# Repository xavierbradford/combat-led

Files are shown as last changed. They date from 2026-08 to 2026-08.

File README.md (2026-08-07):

# Combat Robotics Arena Lighting

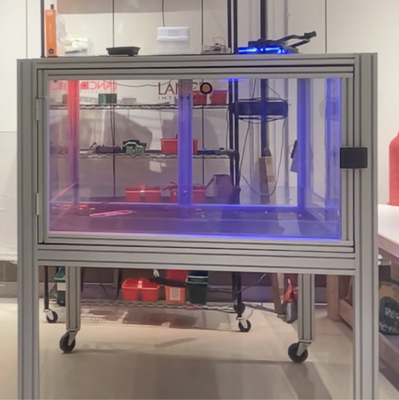
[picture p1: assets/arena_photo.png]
Photo of the arena


The [STEM Coliseum](https://stemcoliseum.org) — where I worked full-time over the summer — runs open antweight combat robotics events, and I thought arena LED effects would make the matches more interesting. The hardware was almost entirely whatever we had lying around the facility, so the choices are unconventional.

I tried to use AI to streamline the development of this project and was surprised that without much help it was able to reverse-engineer the (nonstandard and undocumented) network protocol for the Wi-Fi lights. I used Wireshark to sniff UDP traffic from the proprietary LED control app on my phone to the lights, and described the information I was sending. The AI even automatically determined the parameters in the CRC checksum by writing a Python script to try out common options — very cool!

## Features

- [x] Wi-Fi control of the arena lights
- [x] Web UI
- [x] Infrared control of the match timer
- [x] Impact-reactive lighting effects
- [ ] USB button to advance to the next phase

## Match phases

| Phase | Light & Timer State | Rendering |
| --- | --- | --- |
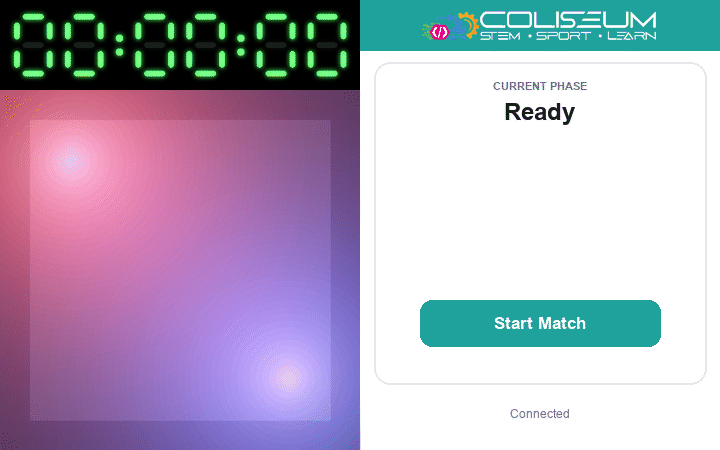
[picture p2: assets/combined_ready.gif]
Ready
| Ready | Red (master) / blue (slave); timer powered on, stopwatch |  |
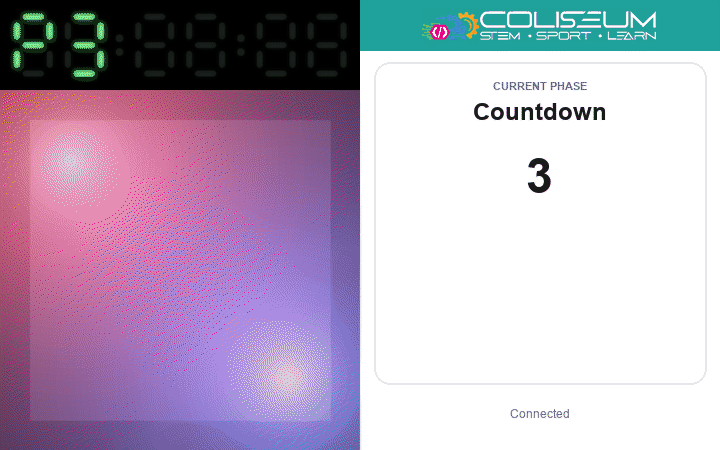
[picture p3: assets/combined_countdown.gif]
Countdown
| Countdown | Red/blue, flashing and fading each second; 3·2·1 countdown |  |
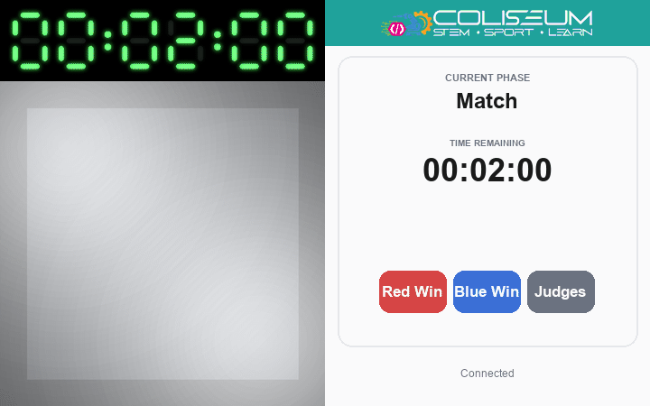
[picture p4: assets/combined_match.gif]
Match
| Match | 100% white, flashing on robot impact; running stopwatch (2 min) |  |
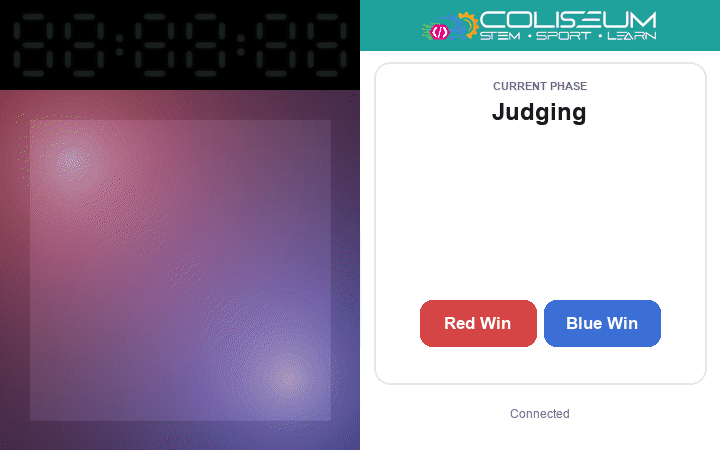
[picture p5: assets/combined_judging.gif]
Judging
| Judging | Red/blue "breathing" alternately; timer off |  |
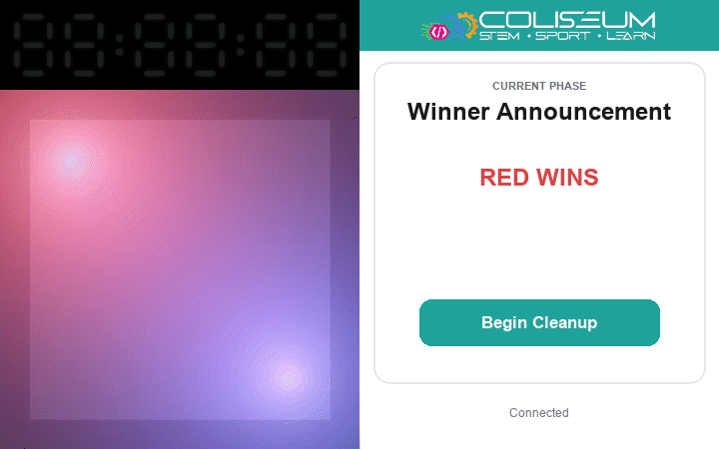
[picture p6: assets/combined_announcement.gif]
Winner Announcement
| Winner Announcement | Alternating, strobe, then hold winner colour; timer off |  |
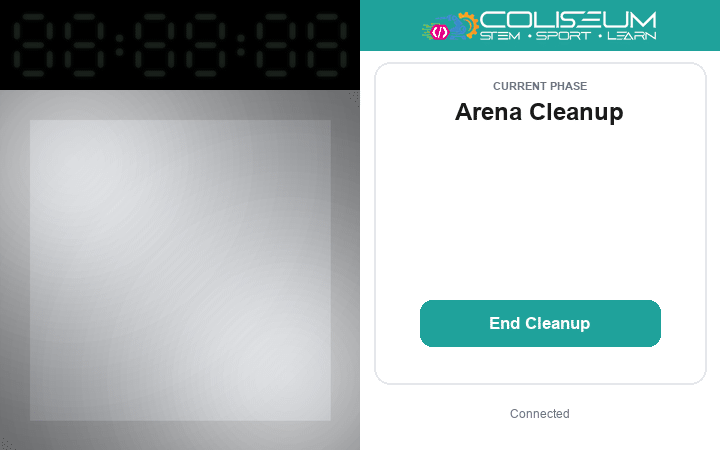
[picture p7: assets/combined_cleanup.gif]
Arena Cleanup
| Arena Cleanup | White, full brightness; timer off |  |

The board boots straight into the Ready phase; after a match it cycles through Arena Cleanup and back to Ready.

Match phase diagram with transitions

## Hardware

- 2× ESP32 dev board — one master, one slave
- 2× Wi-Fi-enabled LED lights (they listen on UDP port 2525)
- Microphone/sound module with analog output (AO) → master GPIO34
- IR transmitter module (e.g. KY-005) → master GPIO4
- Match timer with IR remote
- Jumper wires, breadboard, USB power

The left ESP32 is the master, connected to the microphone, IR transmitter, and (over Wi-Fi) one of the LEDs. The right ESP32 is the slave, connected to the other LED on its separate Wi-Fi network, and receives commands from the master over a serial port.

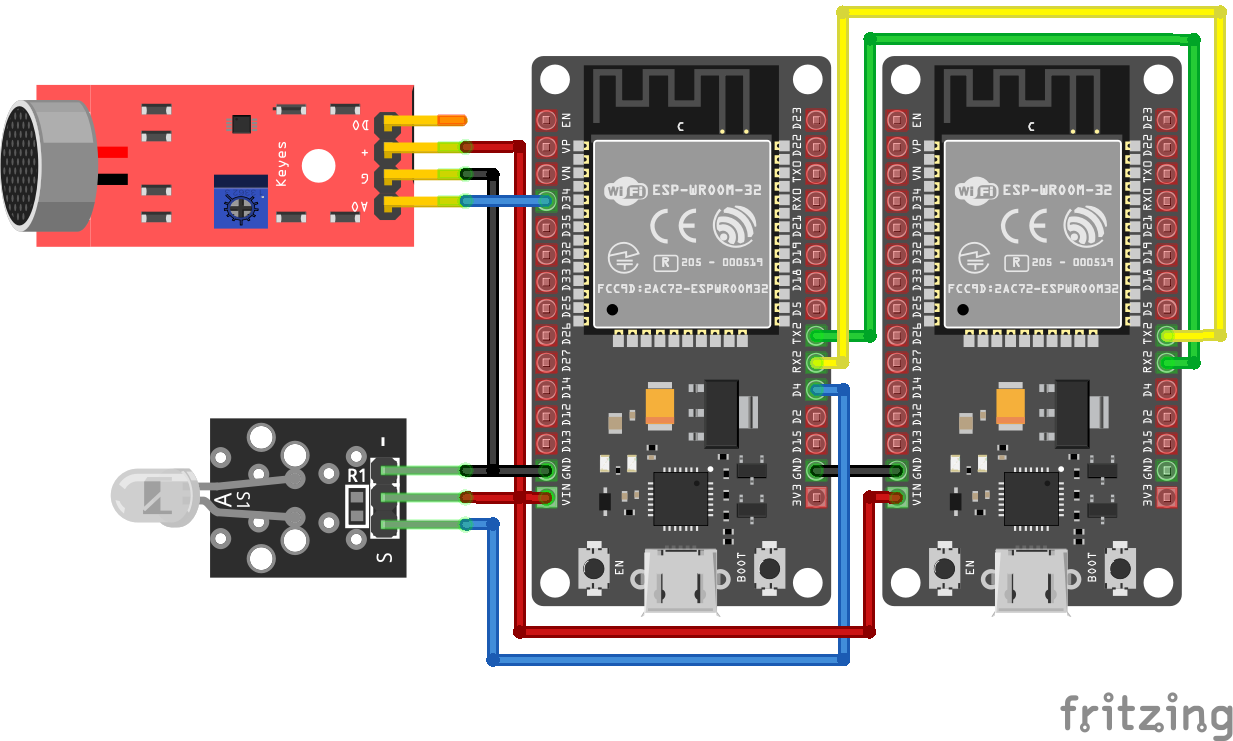
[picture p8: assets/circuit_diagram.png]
Circuit diagram


The master's UART2 connects to the slave's: master TX (GPIO17) → slave RX (GPIO16), master RX (GPIO16) ← slave TX (GPIO17), with a common GND.

## Setup

### Build & flash (no Arduino IDE needed)

You only need Python 3.10+. The first run downloads PlatformIO, the ESP32
toolchain, and the sketch libraries automatically (the master uses ArduinoJson,
AsyncTCP, ESPAsyncWebServer, and IRremote — exact versions are pinned in
`led_master_esp32/platformio.ini`):

```sh
python3 flash.py master          # build + flash the master board
python3 flash.py slave           # build + flash the slave board
python3 flash.py slave --build-only   # compile only, no flashing
python3 flash.py master --monitor     # flash, then open the serial monitor
```

If the board isn't auto-detected, pass its USB port:

```sh
python3 flash.py master --port /dev/tty.usbserial-0001   # macOS / Linux
python3 flash.py slave --port COM3                        # Windows
```

Plug each board into your computer over USB while flashing. Press the board's
`EN`/`RST` button if it doesn't auto-restart afterward.

> `flash.py` works on macOS, Linux, and Windows. Each sketch folder is also a
> self-contained PlatformIO project, so with PlatformIO installed you can run
> `pio run -d led_master_esp32 -t upload` (or `led_slave_esp32`) directly.

### First run

1. Flash the sketch in `led_master_esp32/` to the master board and the one in `led_slave_esp32/` to the slave.
2. Power both boards. Each joins its own light's network (`COMBAT_LED` / `COMBAT_LED2`).
3. Connect to the `COMBAT_LED` network on your phone (password `gvm_admin`).
4. Load the web UI at `http://192.168.4.2`.
> [!TIP]
> If it's not loading, try disabling your mobile data. Your phone might have realised the `COMBAT_LED` network doesn't have access to WAN, and might be trying to resolve the IP through mobile data.
5. Continue through the phases of the match. When you finish one match, it cycles back and is ready for another.

## Customizing

- **Match timings** — `COUNTDOWN_MS` and `MATCH_MS` in `led_master_esp32/led_master_esp32.ino`.
- **Phases and transitions** — the `Phase` enum, `applyAction()`, and the `tickCountdown()`/`tickMatch()` functions define the state machine. The action strings returned by `buttonDefs()` in `led_master_esp32/arena_ui.h` (e.g. `startMatch`, `redWin`, `judges`) must match the cases handled by `applyAction()`.
- **Per-phase lighting** — `updateLightingForPhase()` sets the look when a phase starts; colours, hues, and brightness defaults are hardcoded there (e.g. red = 0°, blue = 240°). `processLightingAnimations()` drives the animated effects (countdown flash, judging "breathing", announcement strobe). Impact flashes during the match are handled by `processMicBrightness()`, tuned by the constants in the `mic` namespace (e.g. `HIT_THRESHOLD`, `FLASH_HOLD_MS`).
- **IR timer control** — the `display` namespace maps the match timer's remote buttons (`BTN_*` constants) and decides when they're pressed in `onPhaseEntered()` and `onCountdownTick()`.
- **Web UI** — all the HTML/CSS/JS is a single header, `led_master_esp32/arena_ui.h`.
- **Networks / Wi-Fi credentials** — the SSID, password, static IP, gateway, subnet, DNS, and bulb broadcast address are all at the top of `led_master_esp32/led_master_esp32.ino` (master) and `led_slave_esp32/led_slave_esp32.ino` (slave).
- **Wired link and adding another light** — the master talks to the slave over UART2 (GPIO16/17 by default) using the framed serial protocol in the `wirelink` namespace; the slave forwards `(selector, value)` frames to its own light. Another slave board is all you'd need to drive a third light; update `linkRxPin`/`linkTxPin`/`linkBaud` in both sketches if you change the wiring.

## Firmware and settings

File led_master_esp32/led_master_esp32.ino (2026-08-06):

/*
 * Dependencies:
 *  Benoit - ArduinoJson@6.21.6
 *  ESP32Async - AsyncTCP@3.5.0
 *  ESP32Async - ESP Async TCP@2.0.0
 *  ESP32Async - ESP Async WebServer@3.11.2
 *  IRremote by shirriff, z3t0, ArminJo v4.7.1
 *
 * These are pinned in platformio.ini for `python3 flash.py master` builds.
 * The sketches need the ESP32 Arduino core 3.x API (<NetworkUdp.h>); the
 * PlatformIO build pulls core 3.x from the pioarduino platform.
 *
 * MASTER ESP32 - connects to its own light's WiFi network, controls that
 * light directly (same protocol as the original app), forwards every
 * command over a wired UART link to the slave board (which relays it to
 * the second light), and hosts a mobile-first match-control web UI.
 */

#include <Arduino.h>
#include <WiFi.h>
#include <NetworkUdp.h>
#include <AsyncTCP.h>
#include <ESPAsyncWebServer.h>
#include <ArduinoJson.h>
#include <IRremote.hpp>
#include "arena_ui.h"

// Forward declarations so the PlatformIO/Arduino-IDE automatic
// function-prototype generators can resolve these types: they are defined
// further down in this file, inside their own namespaces, but the
// generated prototypes are emitted at the top of the file.
namespace arena { struct Snapshot; }
namespace display { enum Button : uint8_t; }

// ---------------------------------------------------------------------
// WiFi credentials
// ---------------------------------------------------------------------
const char *networkName = "COMBAT_LED";
const char *networkPswd = "gvm_admin";

const char *bulbBroadcastAddress = "192.168.4.255";
const uint16_t bulbPort = 2525;

// Static IP so the arena web UI is always reachable at the same address,
// regardless of what IP the bulb's AP (DHCP) hands out.
IPAddress arenaIp(192, 168, 4, 2);
IPAddress arenaGateway(192, 168, 4, 1);
IPAddress arenaSubnet(255, 255, 255, 0);
IPAddress arenaDns(192, 168, 4, 1);

// ---------------------------------------------------------------------
// Serial link to slave board
// ---------------------------------------------------------------------
const unsigned long linkBaud = 3000000;
const int linkRxPin = 16; // GPIO16 = RX2
const int linkTxPin = 17; // GPIO17 = TX2
HardwareSerial SerialLink(2);

boolean connected = false;
NetworkUDP udp;

AsyncWebServer server(80);
AsyncWebSocket ws("/ws");

// ---------------------------------------------------------------------
// LED protocol
// ---------------------------------------------------------------------
namespace led {

// See the forward declarations at the top of this file. The prototype
// generators hoist function declarations to this point, and these bring
// the namespaced types into scope so those hoisted declarations compile.
using arena::Snapshot;
using display::Button;

constexpr uint8_t HEADER[7] = {0x4C, 0x54, 0x09, 0x00, 0x30, 0x57, 0x00};
constexpr uint8_t FIXED_MID = 0x01;

enum class Type : uint8_t {
  Power,
  Channel,
  Hue,
  Brightness,
  Cct,
  Saturation,
};

inline uint16_t crc16CcittFalse(const uint8_t *data, size_t len) {
  uint16_t crc = 0x0000;
  for (size_t i = 0; i < len; i++) {
    crc ^= ((uint16_t)data[i]) << 8;
    for (int b = 0; b < 8; b++) {
      if (crc & 0x8000) {
        crc = (crc << 1) ^ 0x1021;
      } else {
        crc <<= 1;
      }
    }
  }
  return crc;
}

struct Command {
  Type type;
  uint8_t value;

  static Command power(bool on) {
    return Command{Type::Power, (uint8_t)(on ? 1 : 0)};
  }

  static Command channel(uint8_t ch) {
    return Command{Type::Channel, ch};
  }

  static Command hue(uint8_t raw) {
    return Command{Type::Hue, (uint8_t)min((uint32_t)raw, (uint32_t)71)};
  }

  static Command hueFromDegrees(uint16_t degrees) {
    uint16_t deg = degrees % 360;
    uint8_t raw = (uint8_t)min((uint32_t)((deg + 2) / 5), (uint32_t)71);
    return hue(raw);
  }

  static Command brightness(uint8_t percent) {
    return Command{Type::Brightness, (uint8_t)min((uint32_t)percent, (uint32_t)100)};
  }

  static Command cct(uint8_t raw) {
    return Command{Type::Cct, raw};
  }

  static Command cctFromKelvin(uint32_t kelvin) {
    uint32_t raw = (kelvin + 50) / 100;
    if (raw > 255) raw = 255;
    return cct((uint8_t)raw);
  }

  static Command saturation(uint8_t percent) {
    return Command{Type::Saturation, (uint8_t)min((uint32_t)percent, (uint32_t)100)};
  }

  uint8_t selector() const {
    switch (type) {
      case Type::Power:      return 0x00;
      case Type::Channel:    return 0x01;
      case Type::Brightness: return 0x02;
      case Type::Cct:        return 0x03;
      case Type::Hue:        return 0x04;
      case Type::Saturation: return 0x05;
    }
    return 0x00;
  }

  uint8_t valueByte() const {
    return value;
  }

  void dataBytes(uint8_t out[10]) const {
    memcpy(out, HEADER, 7);
    out[7] = selector();
    out[8] = FIXED_MID;
    out[9] = valueByte();
  }

  void toBytes(uint8_t out[12]) const {
    uint8_t data[10];
    dataBytes(data);
    uint16_t crc = crc16CcittFalse(data, 10);
    memcpy(out, data, 10);
    out[10] = (uint8_t)(crc >> 8);
    out[11] = (uint8_t)(crc & 0xFF);
  }

  String toHexString() const {
    uint8_t bytes[12];
    toBytes(bytes);
    char buf[25];
    for (int i = 0; i < 12; i++) {
      sprintf(&buf[i * 2], "%02X", bytes[i]);
    }
    buf[24] = '\0';
    return String(buf);
  }

  bool send(NetworkUDP &sock, const char *addr = nullptr, uint16_t port = 0) const {
    if (addr == nullptr) addr = bulbBroadcastAddress;
    if (port == 0) port = bulbPort;

    String hex = toHexString();
    sock.beginPacket(addr, port);
    sock.write((const uint8_t *)hex.c_str(), hex.length());
    return sock.endPacket() == 1;
  }
};

} // namespace led

// ---------------------------------------------------------------------
// Wired Link Protocol
// ---------------------------------------------------------------------
namespace wirelink {

constexpr uint8_t FRAME_START = 0xA5;

inline uint8_t checksum(uint8_t sel, uint8_t val) {
  return FRAME_START ^ sel ^ val;
}

inline void sendFrame(HardwareSerial &s, uint8_t sel, uint8_t val) {
  uint8_t frame[4] = {FRAME_START, sel, val, checksum(sel, val)};
  s.write(frame, 4);
}

} // namespace wirelink

void sendAndForward(const led::Command &cmd) {
  cmd.send(udp);
  wirelink::sendFrame(SerialLink, cmd.selector(), cmd.valueByte());
}

void send(const led::Command &cmd) {
  cmd.send(udp);
}

void forward(const led::Command &cmd) {
  wirelink::sendFrame(SerialLink, cmd.selector(), cmd.valueByte());
}

// White is produced in RGB mode via saturation(0) - the CCT command
// (selector 0x03) is ignored by these bulbs and leaves them in whatever
// colour they were showing, so it can't be used for white.
void setWhite(uint8_t brightness) {
  sendAndForward(led::Command::saturation(0));
  sendAndForward(led::Command::brightness(brightness));
}

// Defined here so display helpers below can use the enumerators.
namespace arena { enum class Phase : uint8_t { Cleanup, Ready, Countdown, Match, Judging, Announcement }; }

// ---------------------------------------------------------------------
// Fitness Timer Display (IR remote)
// ---------------------------------------------------------------------
namespace display {

// KY-005 S (Signal) pin. On ESP32 any GPIO works for IR output.
constexpr int IR_SEND_PIN = 4;
constexpr uint8_t REMOTE_ADDRESS = 0x01;

enum Button : uint8_t {
  BTN_POWER       = 0x0A,
  BTN_EDIT        = 0x0B,
  BTN_CLOCK       = 0x53,
  BTN_UP          = 0x52,
  BTN_DOWN        = 0x51,
  BTN_STOPWATCH   = 0x50,
  BTN_EMOM        = 0x1B,
  BTN_TABATA      = 0x4B,
  BTN_HIIT        = 0x54,
  BTN_FGB         = 0x4A,
  BTN_ALARM_UP    = 0x43,
  BTN_COLOR_DOWN  = 0x42,
  BTN_START       = 0x5E,
  BTN_RESET       = 0x5D,
  BTN_RESTART     = 0x5B,
  BTN_STOP        = 0x59,
  BTN_ENTER       = 0x5A,
  BTN_EXIT        = 0x41,
  BTN_MUTE        = 0x1A,
  BTN_PREPARATION = 0x57,
  BTN_12_24H      = 0x4F,
  BTN_NUM_0       = 0x03,
  BTN_NUM_1       = 0x0E,
  BTN_NUM_2       = 0x06,
  BTN_NUM_3       = 0x0F,
  BTN_NUM_4       = 0x12,
  BTN_NUM_5       = 0x07,
  BTN_NUM_6       = 0x13,
  BTN_NUM_7       = 0x16,
  BTN_NUM_8       = 0x02,
  BTN_NUM_9       = 0x17,
};

constexpr size_t IR_QUEUE_SIZE = 8;
constexpr uint16_t IR_GAP_MS = 200;

uint8_t irQueue[IR_QUEUE_SIZE];
size_t irQueueHead = 0;
size_t irQueueTail = 0;
unsigned long lastIrSendMs = 0;

bool displayPoweredOn = true;
int lastCountdownDigitSent = -1;

bool enqueue(Button button) {
  size_t next = (irQueueHead + 1) % IR_QUEUE_SIZE;
  if (next == irQueueTail) return false;
  irQueue[irQueueHead] = static_cast<uint8_t>(button);
  irQueueHead = next;
  return true;
}

bool dequeue(uint8_t &button) {
  if (irQueueHead == irQueueTail) return false;
  button = irQueue[irQueueTail];
  irQueueTail = (irQueueTail + 1) % IR_QUEUE_SIZE;
  return true;
}

void begin() {
  IrSender.begin(IR_SEND_PIN);
}

void processQueue() {
  unsigned long now = millis();
  if ((now - lastIrSendMs) < IR_GAP_MS) return;

  uint8_t button;
  if (dequeue(button)) {
    Serial.print("IR send 0x");
    Serial.println(button, HEX);
    IrSender.sendNEC(REMOTE_ADDRESS, button, 0);
    lastIrSendMs = now;
  }
}

void onPhaseEntered(arena::Phase newPhase, arena::Phase oldPhase) {
  if (newPhase == arena::Phase::Countdown) {
    lastCountdownDigitSent = -1;
  }

  switch (newPhase) {
    case arena::Phase::Ready:
      if (oldPhase == arena::Phase::Cleanup) {
        if (!displayPoweredOn) {
          enqueue(BTN_POWER);
          displayPoweredOn = true;
        }
        enqueue(BTN_STOPWATCH);
      }
      break;

    case arena::Phase::Match:
      if (oldPhase == arena::Phase::Countdown) {
        enqueue(BTN_DOWN);
        enqueue(BTN_START);
      }
      break;

    case arena::Phase::Judging:
      if (oldPhase == arena::Phase::Match && displayPoweredOn) {
        enqueue(BTN_POWER);
        displayPoweredOn = false;
      }
      break;

    case arena::Phase::Announcement:
      if (oldPhase == arena::Phase::Match && displayPoweredOn) {
        enqueue(BTN_POWER);
        displayPoweredOn = false;
      }
      break;

    default:
      break;
  }
}

void onCountdownTick(unsigned long remainingMs) {
  int secs = (int)((remainingMs + 999) / 1000); // ceil
  if (secs < 1 || secs > 3 || secs == lastCountdownDigitSent) return;

  Button digit;
  switch (secs) {
    case 3: digit = BTN_NUM_3; break;
    case 2: digit = BTN_NUM_2; break;
    case 1: digit = BTN_NUM_1; break;
    default: return;
  }

  enqueue(digit);
  lastCountdownDigitSent = secs;
}

} // namespace display

// ---------------------------------------------------------------------
// Arena State Machine
// ---------------------------------------------------------------------
namespace arena {

enum class Winner : uint8_t { None, Red, Blue };

struct MatchState {
  // Boot straight into Ready so a fresh event starts on the starting
  // phase; Cleanup is still entered after each match via "Begin Cleanup".
  Phase phase = Phase::Ready;
  Winner winner = Winner::None;
  uint32_t version = 0;
};

struct Snapshot {
  Phase phase;
  Winner winner;
  uint32_t version;
  unsigned long remainingMs;
  unsigned long matchRemainingMs;
};

const unsigned long COUNTDOWN_MS = 3000;
const unsigned long MATCH_MS = 120000; // 2 minutes

MatchState matchState;
unsigned long countdownStartedAt = 0;
unsigned long matchStartedAt = 0;
portMUX_TYPE stateMux = portMUX_INITIALIZER_UNLOCKED;

const char *phaseName(Phase p) {
  switch (p) {
    case Phase::Cleanup:      return "Cleanup";
    case Phase::Ready:        return "Ready";
    case Phase::Countdown:    return "Countdown";
    case Phase::Match:        return "Match";
    case Phase::Judging:      return "Judging";
    case Phase::Announcement: return "Announcement";
  }
  return "Unknown";
}

const char *winnerName(Winner w) {
  switch (w) {
    case Winner::Red:  return "red";
    case Winner::Blue: return "blue";
    default:           return "none";
  }
}

unsigned long remainingCountdownMsLocked() {
  if (matchState.phase != Phase::Countdown) return 0;
  unsigned long elapsed = millis() - countdownStartedAt;
  return (elapsed >= COUNTDOWN_MS) ? 0 : (COUNTDOWN_MS - elapsed);
}

unsigned long remainingMatchMsLocked() {
  if (matchState.phase != Phase::Match) return 0;
  unsigned long elapsed = millis() - matchStartedAt;
  return (elapsed >= MATCH_MS) ? 0 : (MATCH_MS - elapsed);
}

Snapshot snapshot() {
  Snapshot s;
  portENTER_CRITICAL(&stateMux);
  s.phase = matchState.phase;
  s.winner = matchState.winner;
  s.version = matchState.version;
  s.remainingMs = remainingCountdownMsLocked();
  s.matchRemainingMs = remainingMatchMsLocked();
  portEXIT_CRITICAL(&stateMux);
  return s;
}

String toJson(const Snapshot &s) {
  StaticJsonDocument<256> doc;
  doc["phase"] = phaseName(s.phase);
  doc["winner"] = winnerName(s.winner);
  doc["version"] = s.version;
  doc["countdownRemainingMs"] = s.remainingMs;
  doc["matchRemainingMs"] = s.matchRemainingMs;
  doc["serverTime"] = millis();
  String out;
  serializeJson(doc, out);
  return out;
}

bool applyAction(const String &action, uint32_t expectedVersion, Snapshot &outSnap) {
  bool applied = false;
  portENTER_CRITICAL(&stateMux);
  if (matchState.version == expectedVersion) {
    switch (matchState.phase) {
      case Phase::Cleanup:
        if (action == "endCleanup") {
          matchState.phase = Phase::Ready;
          applied = true;
        }
        break;
      case Phase::Ready:
        if (action == "startMatch") {
          matchState.phase = Phase::Countdown;
          matchState.winner = Winner::None;
          countdownStartedAt = millis();
          applied = true;
        }
        break;
      case Phase::Countdown:
        break;
      case Phase::Match:
        if (action == "redWin") {
          matchState.phase = Phase::Announcement;
          matchState.winner = Winner::Red;
          applied = true;
        } else if (action == "blueWin") {
          matchState.phase = Phase::Announcement;
          matchState.winner = Winner::Blue;
          applied = true;
        } else if (action == "judges") {
          matchState.phase = Phase::Judging;
          applied = true;
        }
        break;
      case Phase::Judging:
        if (action == "redWin") {
          matchState.phase = Phase::Announcement;
          matchState.winner = Winner::Red;
          applied = true;
        } else if (action == "blueWin") {
          matchState.phase = Phase::Announcement;
          matchState.winner = Winner::Blue;
          applied = true;
        }
        break;
      case Phase::Announcement:
        if (action == "newMatch") {
          matchState.phase = Phase::Cleanup;
          matchState.winner = Winner::None;
          applied = true;
        }
        break;
    }
    if (applied) matchState.version++;
  }
    outSnap.phase = matchState.phase;
    outSnap.winner = matchState.winner;
    outSnap.version = matchState.version;
    outSnap.remainingMs = remainingCountdownMsLocked();
    outSnap.matchRemainingMs = remainingMatchMsLocked();
    portEXIT_CRITICAL(&stateMux);
    return applied;
}

bool tickCountdown() {
  bool changed = false;
  portENTER_CRITICAL(&stateMux);
  if (matchState.phase == Phase::Countdown &&
      (millis() - countdownStartedAt) >= COUNTDOWN_MS) {
    matchState.phase = Phase::Match;
    matchState.version++;
    matchStartedAt = millis();
    changed = true;
  }
  portEXIT_CRITICAL(&stateMux);
  return changed;
}

bool tickMatch() {
  bool changed = false;
  portENTER_CRITICAL(&stateMux);
  if (matchState.phase == Phase::Match &&
      (millis() - matchStartedAt) >= MATCH_MS) {
    matchState.phase = Phase::Judging;
    matchState.version++;
    changed = true;
  }
  portEXIT_CRITICAL(&stateMux);
  return changed;
}

} // namespace arena

void updateLightingForPhase(const arena::Snapshot &snap);

// ---------------------------------------------------------------------
// Arena Web Server & Websocket setup
// ---------------------------------------------------------------------
bool arenaServerStarted = false;

void startArenaServer() {
  if (arenaServerStarted) return;
  arenaServerStarted = true;

  server.on("/", HTTP_GET, [](AsyncWebServerRequest *request) {
    request->send_P(200, "text/html", INDEX_HTML);
  });

  server.on("/api/state", HTTP_GET, [](AsyncWebServerRequest *request) {
    request->send(200, "application/json", arena::toJson(arena::snapshot()));
  });

  server.on(
      "/api/action", HTTP_POST,
      [](AsyncWebServerRequest *request) {},
      nullptr,
      [](AsyncWebServerRequest *request, uint8_t *data, size_t len, size_t index, size_t total) {
        if (index == 0) {
          request->_tempObject = new String();
        }
        String *body = reinterpret_cast<String *>(request->_tempObject);
        body->concat((const char *)data, len);
        if (index + len != total) return;

        StaticJsonDocument<128> in;
        DeserializationError err = deserializeJson(in, *body);
        String action = err ? String("") : String((const char *)(in["action"] | ""));
        uint32_t expectedVersion = err ? 0 : (uint32_t)(in["version"] | 0);
        delete body;
        request->_tempObject = nullptr;

        arena::Snapshot snap;
        bool applied = arena::applyAction(action, expectedVersion, snap);
        String out = arena::toJson(snap);

        request->send(applied ? 200 : 409, "application/json", out);
        if (applied) {
          ws.textAll(out);
          updateLightingForPhase(snap);
        }
      });

  ws.onEvent([](AsyncWebSocket *server, AsyncWebSocketClient *client, AwsEventType type,
                void *arg, uint8_t *data, size_t len) {
    if (type == WS_EVT_CONNECT) {
      client->text(arena::toJson(arena::snapshot()));
    }
  });
  server.addHandler(&ws);

  server.begin();
  Serial.println("Arena web UI started");
}

// ---------------------------------------------------------------------
// Microphone Sound Detection
// ---------------------------------------------------------------------
// The sound sensor module's AO output is an audio waveform riding on a
// DC quiescent point. Loudness is measured as the peak-to-peak swing of
// the ADC samples over a rolling window - the same AMP value printed by
// the sound_sensor_test sketch. During a Match the lights sit at a
// default 100% white; any sound above the threshold snaps them to a
// full-brightness red/blue flash for at least FLASH_HOLD_MS.
namespace mic {

constexpr int AO_PIN = 34;                // ADC1_CH6, input-only, unused by master
constexpr unsigned long WINDOW_MS = 40;   // rolling loudness window
constexpr unsigned long SAMPLE_INTERVAL_MS = 2; // ~500 Hz sampling
constexpr int HIT_THRESHOLD = 60;         // amplitude that counts as a hit
constexpr unsigned long FLASH_HOLD_MS = 50; // minimum flash duration

// Default (quiet) look for the Match phase.
constexpr int DEFAULT_BRIGHTNESS = 100;

int minVal = 4095;
int maxVal = 0;
unsigned long lastSampleMs = 0;
unsigned long windowStartMs = 0;

void begin() {
  analogReadResolution(12);
  analogSetPinAttenuation(AO_PIN, ADC_11db);
}

// Call once per loop() pass. Returns the loudness of the last completed
// sampling window, or -1 if no window has finished since the last call.
int readAmplitude() {
  unsigned long now = millis();
  if ((now - lastSampleMs) < SAMPLE_INTERVAL_MS) return -1;
  lastSampleMs = now;

  int v = analogRead(AO_PIN);
  if (v < minVal) minVal = v;
  if (v > maxVal) maxVal = v;

  if ((now - windowStartMs) < WINDOW_MS) return -1;

  int amplitude = maxVal - minVal;
  minVal = 4095;
  maxVal = 0;
  windowStartMs = now;
  return amplitude;
}

} // namespace mic

// ---------------------------------------------------------------------
// Non-Blocking Lighting State Controller
// ---------------------------------------------------------------------
enum class AnnounceStep { Alternating, Strobe, HoldWinner };
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
void loop() {
  if (!connected) return;

  bool changed = arena::tickCountdown();
  changed |= arena::tickMatch();

  arena::Snapshot snap = arena::snapshot();

  if (changed) {
    ws.textAll(arena::toJson(snap));
    updateLightingForPhase(snap);
    lastCountdownBroadcast = millis();
  } else {
    if (snap.phase == arena::Phase::Countdown &&
        (millis() - lastCountdownBroadcast) >= COUNTDOWN_TICK_MS) {
      lastCountdownBroadcast = millis();
      ws.textAll(arena::toJson(snap));
    }
  }

  if (snap.phase == arena::Phase::Countdown) {
    display::onCountdownTick(snap.remainingMs);
  }

  processLightingAnimations(snap.remainingMs);
  processMicBrightness();
  display::processQueue();
}

void connectToWiFi(const char *ssid, const char *pwd) {
  Serial.println("Connecting to WiFi network: " + String(ssid));

  WiFi.disconnect(true);
  WiFi.onEvent(WiFiEvent);
  WiFi.config(arenaIp, arenaGateway, arenaSubnet, arenaDns);
  WiFi.begin(ssid, pwd);

  Serial.println("Waiting for WIFI connection...");
}

void WiFiEvent(WiFiEvent_t event) {
  switch (event) {
    case ARDUINO_EVENT_WIFI_STA_GOT_IP:
      Serial.print("WiFi connected! IP address: ");
      Serial.println(WiFi.localIP());
      udp.begin(WiFi.localIP(), bulbPort);
      connected = true;
      startArenaServer();
      updateLightingForPhase(arena::snapshot());
      break;
    case ARDUINO_EVENT_WIFI_STA_DISCONNECTED:
      Serial.println("WiFi lost connection");
      connected = false;
      break;
    default:
      break;
  }
}

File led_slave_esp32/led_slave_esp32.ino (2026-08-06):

/*
 * SLAVE ESP32 - connects to its own light's WiFi network and forwards
 * (selector, value) commands received over a wired UART link as
 * properly-formatted UDP packets to that light.
 *
 * The master/slave sync happens entirely over the wired serial link
 * between the two ESP32 boards (UART2, pins 16/17 by default) - not over
 * the lights' own WiFi broadcast protocol. Each board only ever talks to
 * the single light it's joined to.
 *
 * Wiring between the two boards:
 *   this board TX2 (GPIO17) -> master board RX2 (GPIO16)
 *   this board RX2 (GPIO16) <- master board TX2 (GPIO17)
 *   this board GND          -- master board GND   (must be common!)
 *
 * Packet layout sent to the light (10 data bytes + 2 byte CRC, sent as 24
 * ASCII hex chars):
 *
 *   4C 54 09 00 30 57 00 SEL 01 VAL CRC_HI CRC_LO
 *   \_____ fixed header ____/  |   |   |
 *                              |   |   `- value (meaning depends on SEL)
 *                              |   `----- constant, always 0x01 in captures
 *                              `--------- selector: which control is being set
 *
 * CRC is CRC-16/CCITT-FALSE (poly 0x1021, init 0x0000, no reflect, no xorout)
 * over the 10 data bytes, big-endian in the packet.
 *
 * NOTE: SEL=0x02 and SEL=0x05 are both confirmed to be plain 0-100 percentage
 * controls, but which one is Brightness vs Saturation hasn't been confirmed
 * yet - swap the selectors in ledSelector() below if it turns out backwards.
 *
 * ---------------------------------------------------------------------
 * Wired link protocol (this board <-> master board): framed frames, not
 * bare bytes. See the `wirelink` namespace below for the full rationale and
 * format - short version: each (selector, value) pair is wrapped in a
 * 4-byte frame with a start byte and checksum, so the receiver can detect
 * corruption and resynchronize on its own after a dropped byte, a noisy
 * wire, or the cable being unplugged and replugged - no handshake needed.
 * ---------------------------------------------------------------------
 */

#include <Arduino.h>
#include <WiFi.h>
#include <NetworkUdp.h>

// ---------------------------------------------------------------------
// WiFi credentials - THIS board's own light's network.
// ---------------------------------------------------------------------
const char *networkName = "COMBAT_LED2";
const char *networkPswd = "gvm_admin";

// The bulb listens for UDP broadcasts on this port. The broadcast address
// matches the subnet seen in the original captures (192.168.4.255) -
// change this if your bulb/router uses a different subnet.
const char *bulbBroadcastAddress = "192.168.4.255";
const uint16_t bulbPort = 2525;

// ---------------------------------------------------------------------
// Serial link to the master board (UART2, NOT the USB debug Serial).
// ---------------------------------------------------------------------
// ESP32 UART hardware supports up to 5,000,000 baud. 3,000,000 is used
// here as a safer default over breadboard/jumper wiring; bump it to
// 5000000 if your wiring is short and clean. For 4-byte frames sent
// occasionally, baud rate barely matters for throughput - this is mostly
// about minimizing latency, and either value is already far faster than
// the WiFi hop that follows it.
const unsigned long linkBaud = 3000000;
const int linkRxPin = 16; // GPIO16 = RX2
const int linkTxPin = 17; // GPIO17 = TX2
HardwareSerial SerialLink(2);

boolean connected = false;
NetworkUDP udp;

// ---------------------------------------------------------------------
// LED protocol (light-facing UDP packet, unchanged)
// ---------------------------------------------------------------------
namespace led {

constexpr uint8_t HEADER[7] = {0x4C, 0x54, 0x09, 0x00, 0x30, 0x57, 0x00};
constexpr uint8_t FIXED_MID = 0x01; // byte 8, constant in every capture so far

enum class Type : uint8_t {
  Power,
  Channel,
  Hue,
  Brightness,
  Cct,
  Saturation,
};

// CRC-16/CCITT-FALSE: poly 0x1021, init 0x0000, no input/output reflection,
// no final XOR.
inline uint16_t crc16CcittFalse(const uint8_t *data, size_t len) {
  uint16_t crc = 0x0000;
  for (size_t i = 0; i < len; i++) {
    crc ^= ((uint16_t)data[i]) << 8;
    for (int b = 0; b < 8; b++) {
      if (crc & 0x8000) {
        crc = (crc << 1) ^ 0x1021;
      } else {
        crc <<= 1;
      }
    }
  }
  return crc;
}

// Build and send a frame directly from a raw (selector, value) pair - this
// is what the slave uses for everything it receives over the serial link,
// since the wire format only ever needs those two bytes regardless of
// what they semantically mean. Only called once the link layer below has
// already validated the pair, so no further range-checking happens here.
inline bool sendRaw(NetworkUDP &sock, uint8_t selector, uint8_t value,
                     const char *addr = nullptr, uint16_t port = 0) {
  if (addr == nullptr) addr = bulbBroadcastAddress;
  if (port == 0) port = bulbPort;

  uint8_t data[10];
  memcpy(data, HEADER, 7);
  data[7] = selector;
  data[8] = FIXED_MID;
  data[9] = value;

  uint16_t crc = crc16CcittFalse(data, 10);
  uint8_t bytes[12];
  memcpy(bytes, data, 10);
  bytes[10] = (uint8_t)(crc >> 8);
  bytes[11] = (uint8_t)(crc & 0xFF);

  char buf[25];
  for (int i = 0; i < 12; i++) {
    sprintf(&buf[i * 2], "%02X", bytes[i]);
  }
  buf[24] = '\0';

  Serial.printf("relaying sel=0x%02X val=0x%02X -> %s\n", selector, value, buf);

  sock.beginPacket(addr, port);
  sock.write((const uint8_t *)buf, 24);
  return sock.endPacket() == 1;
}

} // namespace led
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

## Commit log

2026-08-06 Initial commit: Coliseum arena LED match control, web UI, and preview assets
    [circuit.fzz]
2026-08-07 Rename images/ to assets/, keep editable Fritzing source
    [circuit.fzz]
